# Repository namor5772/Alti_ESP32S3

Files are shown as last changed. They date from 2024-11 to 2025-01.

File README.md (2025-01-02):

This is a repository for my digital altimeter based on the ESP32-S3 microcontroller. It uses an I2C interfaced pressure/temperature sensor board based on the MS5637 chip and an 84x48 SPI interfaced lcd screen based on the PCD8544 chip. The electronics is housed in the enclosure used by an old analog skydiving altimeter. Eveything is powered by a single cell LiPo battery that can be charged by a USB-C port. This can also be used to update the software.

When switched on the altimeter sets to zero, giving the height above ground in thousands of feet or alternately relative to the standard sea level pressure of 1013.25 mb. It displays the height in large numerical characters to the nearest 100 feet, with the remaining altitude < 100 ft in a very small font. Negative altitudes are displayed as required.

In addition the voltage x 10 is displayed in a tiny font at the top right of the screen, under it is displayed the approximate air temperature also in a tiny font. If the battery voltage drop below 3.2V (32 displayed) the voltage displayed is replaced by a flashing block. "Latching" is implemented in code to prevent the display alternating with voltage and flashing block.

The switch for the altimiter is actually a momentary push button and does not physically disconnect/connect the battery from the circuit, it just toggles between the microcontrollers normal and deep sleep states. In the deep sleep state the circuit uses minimal current of around 18µA and should last about a year before recharging. In order that one does not accidentally switch the altimeter off, doing so requires the switch to be pressed twice within a very specific and narrow time gap range. This is indicated by temporary and self explanatory messages displayed on the screen.

It has been successfully tested in freefall!

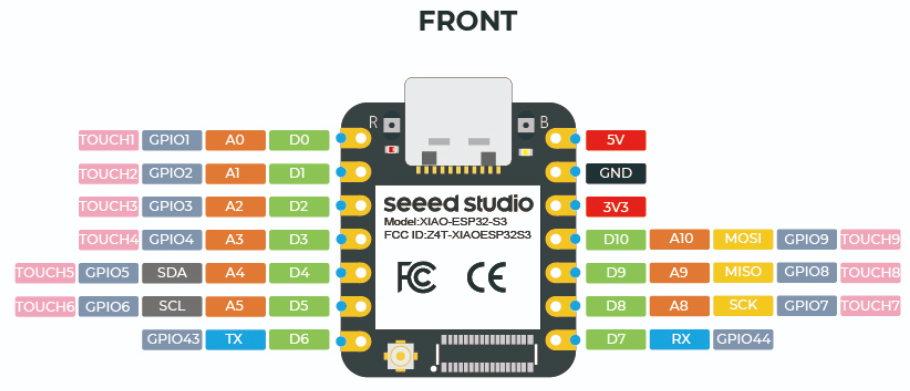
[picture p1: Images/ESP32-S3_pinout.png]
ESP32-S3 pinout


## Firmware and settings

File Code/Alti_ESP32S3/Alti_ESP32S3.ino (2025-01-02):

#include "MS5637.h"
#include "PCD8544.h"
#include "Font.h"

#include <Preferences.h>
#include <esp_sleep.h>
#include <esp32-hal-gpio.h>

// Define DEBUG to enable debug mode
#define DEBUG

// To Do :
// done 1. Make nicer big numbers font for displaying Altitude
// done 2. Test Deep-Sleep functionality
// 3. implement 3x button press Deep-Sleep functionality, with random delays

// Define the analog pin connected to the voltage divider
#define BATTERY_PIN 8 // GPIO8 (A9)

// Define the pin connected to a momentary button, to toggle
// deep-sleep mode for trhis altimeter, as an alternative to
// a physical switch that disconnects LiPo battery.
#define ONOFF_PIN 7 // GPIO7 (D8)

// Nokia 5772 - PCD8544 driver chip
// and pinout to SEED ESP32s3 MICRO
// 1 - VCC (3v3)
// 2 - GND
// 3 - SCE (CE)       - GPIO1 D0
// 4 - RST (RST)      - GPIO2 D1
// 5 - D/C (DC)       - GPIO3 D2
// 6 - DN<MOSI> (DIN) - GPIO4 D3 
// 7 - SCLK (CLK)     - GPIO9 D10
// 8 - LED 
// An instance called lcd of the PCD8544 class is created
// The module uses an enhanced bit-bashed 3-Wire SPI communications protcol
// The specified pins are: CLK, MOS, RES, DC, CS.
#define RST 2
#define CE 1
#define DC 3
#define DIN 4
#define CLK 9
PCD8544 lcd{RST, CE, DC, DIN, CLK};

// An instance of the MS5637 class called BARO is created
// The address and micro pins are defined in the MS5637.h file
// The module is I2C and has just 4 pins:
// 1 GND - connect to ground pin on micro (Seeed ESP32S3 here)
// 2 SDA - connect to SDA pin on micro (also called GPIO5 & D4)
// 3 SCL - connect to SCL pin on micro (also called GPIO6 & D5)
// 4 VCC - connect to 3V3 pin on micro
MS5637 BARO;

// *** global variables ***
bool isGround;
uint32_t chipId = 0;
uint16_t adcRaw;
float temp, pressure, altBase, altRel, batVol;
// related to safely shutting down the altimeter
int pressNum = 0;
bool keyPressed = false;
bool keyPressedAgain = false;
bool Redraw = false;
int tryNum = 0;
uint32_t startTime, elapsedTime;
int randomDelay;


void setup() {
  startTime = millis();
  Serial.begin(115200);

  // initialize digital pin LED_BUILTIN as an output
  // and turn the LED off (ie. HIGH) by default
  pinMode(LED_BUILTIN, OUTPUT);
  digitalWrite(LED_BUILTIN, HIGH);

  // setup deep-sleep on/off pin,
  // actually need an external pull-up (4.7k)
  pinMode(ONOFF_PIN,INPUT_PULLUP);

  // reads the persistent isGround boolean value
  Preferences preferences;
  preferences.begin("alti_prefs", false);
  bool isGround = preferences.getBool("isGround", false);

  // setup MS5637 sensor (An instance of the MS5637 object BARO has been constructed above)
  BARO.begin();
  BARO.dumpDebugOutput();
  BARO.getTempAndPressure(&temp, &pressure);

  // toggles mode as ground or absolute between powering altimeter
  if (isGround) {
    altBase = BARO.pressure2altitude(pressure);
    preferences.putBool("isGround", false);
  }
  else { // if not isGround
    altBase = 0.0;
    preferences.putBool("isGround", true);
  }
 
  // setup lcd screen and display splash screen for 3 seconds
  // then clear in readiness for normal data display
  lcd.setDisplayMode(NORMAL);
  lcd.setContrast(60);
  lcd.print("Alti ESP32v2.0 Nov24");
  lcd.print("----------");
  lcd.setCursor(0, 3);
  lcd.print("Roman M   Groblicki ");
  lcd.print("----------");
  delay(3000);
  lcd.clear();
}


void loop() {
  // is key pressed ?
  keyPressed = (digitalRead(ONOFF_PIN)==LOW); 


// *** START - obtaining, processing and displaying data on screen

  if (!BARO.isOK()) {
    // Try to reinitialise the sensor if we can and measure temperature and pressure
    BARO.begin();
    BARO.getTempAndPressure(&temp, &pressure);
  }
  else { // just normal measurements on each loop
    BARO.getTempAndPressure(&temp, &pressure);
  }

  // Calculate and display the altitude relative to where the altimeter was turned on
  altRel = BARO.pressure2altitude(pressure) - altBase; 
  if (altRel < 0.0) altRel = -1.0*altRel; // take the absolute value 
  lcd.Altitude_largefont(altRel, Redraw);

  // display current temperature measured by the MS5637 (and used to
  // improve calculation of air pressure above)
  temp = temp - 0.5; // fudjustment for circuit temp being above ambient
  lcd.Temperature_tinyfont(temp, 1, 76, Redraw);

  // Read raw ADC value, convert to battery voltage and display both
  adcRaw = analogRead(BATTERY_PIN);
  batVol = adcRaw*0.000903509+0.460132; // 0.287561; // raw adc to battery voltage conversion
  if (batVol>3.19){
    // just display battery voltage
    lcd.Battery_tinyfont(batVol, 0, 76, Redraw);
  }
  else { //battery voltage too low so indicate need to charge LiPo
    // flash a block in the battery voltage display position
    // half second on, half second off.
    float mTime = millis();
    mTime = mTime-floor(mTime/1000.0)*1000.0;
    bool isFlash = false;
    if (mTime<500.0) isFlash = true;
    lcd.BatteryFlash_tinyfont(isFlash, 0, 76, Redraw);
  }

// *** END - obtaining, processing and displaying data on screen

  Redraw = false;

// *** START - dealing with trying to shut down altimeter ***

  if ((pressNum > 0) && (!keyPressed)) {
    lcd.clear(); delay(50);

#ifdef DEBUG
    Serial.print(F("PRESS AGAIN "));
    Serial.println(pressNum);
#endif    

    lcd.print("----------");
    lcd.print("--PRESS---");
    lcd.print("--AGAIN---");    
    lcd.print("--NOW!!---");
    lcd.print("----------");
    lcd.print("----------");
    delay(100);

    // is key pressed again?
    tryNum = 0;
    Serial.println(tryNum);
    keyPressedAgain = (digitalRead(ONOFF_PIN)==LOW);
    while ((!keyPressedAgain) && (tryNum<10)) {
      delay(100);
      keyPressedAgain = (digitalRead(ONOFF_PIN)==LOW);
      tryNum++;
      Serial.println(tryNum);
    }
    lcd.clear();
    
    // make this delay slightly random, say between 1 and 5 seconds,
    // unless it is the 2nd press in which case can just make it 1second
    if (pressNum==2) {
      delay(1000);
    }
    else {
      randomDelay = 10*random(100,501);
      Serial.println(randomDelay);
      delay(randomDelay);
    }

    pressNum++;
    if (!keyPressedAgain) {
      Serial.println(F("MISSED"));
      lcd.print("          ");
      lcd.print("          ");
      lcd.print("  MISSED  ");
      delay(2000);
      lcd.clear();
      pressNum = 0;
      Redraw = true;
    }      
  }
  else if ((pressNum > 0) && (keyPressed)) {
    // kept button pressed too long so reset attempt to shut down
    delay(500);
    pressNum==0;
    keyPressed = false;
    Redraw = true;
  }

  if (keyPressed || keyPressedAgain ){
    if (pressNum==0) {
      // clear and display 'shutdown' screen for 2 seconds then clear again
      lcd.clear(); delay(50);
      Serial.println(F("SHUTTING DOWN INTO DEEP SLEEP"));
      lcd.print("----------");
      lcd.print("-SHUTTING-");
      lcd.print("---DOWN---");    
      lcd.print("---INTO---");
      lcd.print("DEEP SLEEP");
      lcd.print("----------");

      // make this delay slightly random, say between 1 and 5 seconds
      // we randomly seed the random generator here
      // for use here and and the next keypress.
      elapsedTime = millis() - startTime;
      randomSeed(elapsedTime);
      randomDelay = 10*random(100,501);

      Serial.println(randomDelay);
      
      delay(randomDelay);
      lcd.clear();

      pressNum = 1;
      Redraw = true;
    }
    else if (pressNum==3) {
      lcd.clear(); delay(50);
      Serial.println(F("SHUTTING DOWN FOR REAL"));
      lcd.print("----------");
      lcd.print("-SHUTTING-");
      lcd.print("---DOWN---");    
      lcd.print("--4-REAL--");
      lcd.print("----------");
      lcd.print("----------");
      delay(2000);

      // Enable EXT0 wake-up source (wake up when pin goes LOW) 
      esp_sleep_enable_ext0_wakeup(GPIO_NUM_7, 0);

      // Enter deep sleep mode 
      esp_deep_sleep_start();
    }
  } 

// *** END - dealing with trying to shut down altimeter ***

  delay(50);
}

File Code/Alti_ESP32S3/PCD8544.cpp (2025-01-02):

#include "Arduino.h"
#include "PCD8544.h"
#include "Font.h"


PCD8544::PCD8544(uint8_t RST, uint8_t CE, uint8_t DC, uint8_t DIN, uint8_t CLK):
  _RST(RST), _CE(CE), _DC(DC), _DIN(DIN), _CLK(CLK) {

  pinMode(RST, OUTPUT);
  pinMode(CE, OUTPUT);
  pinMode(DC, OUTPUT);
  pinMode(DIN, OUTPUT);
  pinMode(CLK, OUTPUT);

  // screen initializations  
  reset();
  clear();
  setDisplayMode(NORMAL);
  setBiasSystem(FORTY);
  setContrast(60);

  // initialise str_old*, for its first use in loop(),
  // size is enough to store 10 characters, but often less is used.
  for (int i=0; i<10; i++) {
    str_old[i] = ' ';  
    str_old0[i] = ' ';
    str_old1[i] = ' ';
    str_old2[i] = ' ';
    str_old3[i] = ' ';
    str_old4[i] = ' ';
  }        
}

// contrast c should be between 0x00 and 0x7F inclusive (127 decimal) 
void PCD8544::setContrast(uint8_t c){
    digitalWrite(_CE, LOW); // CS (Upper score)
    digitalWrite(_DC, LOW); // select Command Mode - A0 set as LOW
    shiftOut(_DIN, _CLK, MSBFIRST, ADVANCED); // use extended instruction set
    shiftOut(_DIN, _CLK, MSBFIRST, byte(0x80 + c));
    digitalWrite(_CE, HIGH);
}

// Temperature Coefficient value could be one of 0, 1, 2 or 3;
void PCD8544::setTemperatureCoefficient(uint8_t value){
    digitalWrite(_CE, LOW); // CS (Upper score)
    digitalWrite(_DC, LOW); // select Command Mode - A0 set as LOW
    shiftOut(_DIN, _CLK, MSBFIRST, ADVANCED); // use extended instruction set
    shiftOut(_DIN, _CLK, MSBFIRST, byte(0x04 + value));
    digitalWrite(_CE, HIGH);
}

void PCD8544::setCursor(uint8_t x, uint8_t y){
    Xcur = x; Ycur = y;
    digitalWrite(_CE, LOW); // CS (Upper score)
    digitalWrite(_DC, LOW); // select Command Mode - A0 set as LOW
    shiftOut(_DIN, _CLK, MSBFIRST, BASIC); // use basic instruction set
    shiftOut(_DIN, _CLK, MSBFIRST, byte(0x80 + x)); //set x position
    shiftOut(_DIN, _CLK, MSBFIRST, byte(0x40 + y)); //set y position
    digitalWrite(_CE, HIGH);
}

void PCD8544::clear(){
    Xcur = 0; Ycur = 0;
    digitalWrite(_CE, LOW); // CS (Upper score)
    digitalWrite(_DC, LOW); // select Command Mode - A0 set as LOW
    shiftOut(_DIN, _CLK, MSBFIRST, BASIC); // use basic instruction set
    shiftOut(_DIN, _CLK, MSBFIRST, byte(0x80)); //set x position to 0
    shiftOut(_DIN, _CLK, MSBFIRST, byte(0x40)); //set y position to 0
    digitalWrite(_DC, HIGH); // select Data Mode - A0 set to HIGH
        for (int i=0; i<504; i++) shiftOut(_DIN, _CLK, MSBFIRST, 0x00);
    digitalWrite(_CE, HIGH);
    // at this point cursor has cycled back to (0,0)
}

void PCD8544::setDisplayMode(byte value){
    digitalWrite(_CE, LOW); // CS (Upper score)
    digitalWrite(_DC, LOW); // select Command Mode - A0 set as LOW
    shiftOut(_DIN, _CLK, MSBFIRST, BASIC); // use basic instruction set
    shiftOut(_DIN, _CLK, MSBFIRST, value); // set display configuration
    digitalWrite(_CE, HIGH);
}

void PCD8544::setBiasSystem(byte rate){
    digitalWrite(_CE, LOW); // CS (Upper score)
    digitalWrite(_DC, LOW); // select Command Mode - A0 set as LOW
    shiftOut(_DIN, _CLK, MSBFIRST, ADVANCED); // use extended instruction set
    shiftOut(_DIN, _CLK, MSBFIRST, rate); // set bias system
    digitalWrite(_CE, HIGH);
}

// displays a block of data to screen, at top-left-hand position (page, col),
// ie pixel row is pagex8 and pixel column is col.
// the height is pages high (ie pagesx8 pixels) and cols pixels wide.
// the data (in vertical-encoding) is stored in a 1d array of bytes called Arr,
// while the offset for individual bytes (to display) is address which has to be uint16_t
// since the array might have more than 256 elements.
void PCD8544::writeBlock(uint8_t page, uint8_t col, uint8_t pages, uint8_t cols, uint16_t address, const uint8_t Arr[]) {
  uint8_t columnByte;
  digitalWrite(_CE, LOW); // CS (Upper score)
  for (uint8_t j = 0; j < pages; j++) {
    digitalWrite(_DC, LOW); // select Command Mode - A0 set as LOW
    shiftOut(_DIN, _CLK, MSBFIRST, BASIC); // use basic instruction set
    shiftOut(_DIN, _CLK, MSBFIRST, byte(0x80 + col));      //set x position
    shiftOut(_DIN, _CLK, MSBFIRST, byte(0x40 + page + j)); //set y position

    digitalWrite(_DC, HIGH); // Datamode - A0 set to HIGH
    for (uint8_t i = 0; i < cols; i++)  {
      columnByte = pgm_read_byte(&Arr[address + cols*j + i]);
      shiftOut(_DIN, _CLK, MSBFIRST, columnByte);
    }
  }
  digitalWrite(_CE, HIGH);
}

void PCD8544::write8x8Char(uint8_t page, uint8_t column, uint16_t charCode, const uint8_t Arr[][8]) {
  uint8_t columnByte;
  digitalWrite(_CE, LOW); // CS (Upper score)

  digitalWrite(_DC, LOW); // select Command Mode - A0 set as LOW
  shiftOut(_DIN, _CLK, MSBFIRST, BASIC); // use basic instruction set
  shiftOut(_DIN, _CLK, MSBFIRST, byte(0x80 + column)); //set x position
  shiftOut(_DIN, _CLK, MSBFIRST, byte(0x40 + page));   //set y position

  digitalWrite(_DC, HIGH); // Datamode - A0 set to HIGH
  for (uint8_t i = 0; i < 8; i++)  {
    columnByte = pgm_read_byte(&Arr[charCode][i]);
    shiftOut(_DIN, _CLK, MSBFIRST, columnByte);
  }

  digitalWrite(_CE, HIGH);
}

// generate and display formatted string for temperature temp_,
// but for speed only redisplay changed characters.
void PCD8544::Temperature(float temp_, uint8_t page, uint8_t col) {
  int w = 5; // width of text in characters
  if (temp_<=-10.0) {
    dtostrf(temp_,3,0,str_new0);  
    str_new0[3] = 0x00; // degree character
    w--;
  } else {
    dtostrf(temp_,4,1,str_new0);
    str_new0[4] = 0x00; // degree character
  }
  for (int i=0; i<w; i++) {
    if (str_new0[i] != str_old0[i]) {
      write8x8Char(page, col+i*8, str_new0[i], Font8x8_);
      str_old0[i] = str_new0[i]; // after loop finish make str_old0 the current str_new0
    }      
  }
}

// generate and display formatted string for temperature temp_,
// but for speed only redisplay changed characters.
// minimal display using only 2 chars with 0dp. if <=-10 then no sign.
void PCD8544::Temperature_tinyfont(float temp_, uint8_t page, uint8_t col, bool Redraw) {
  if (temp_<=-10.0) temp_ = -1.0 * temp_*-1.0;
  dtostrf(temp_,2,0,str_new0);
  str_new2[2] = 0;  
  for (int i=0; i<2; i++) {
    if ((str_new0[i] != str_old0[i]) || Redraw) {
      writeBlock(page, col+4*i, 1, 4,  ASCII2offset(str_new0[i], 0x0004), FontNums3x5);
      str_old0[i] = str_new0[i]; // after loop finish make str_old0 the current str_new0
    }      
  }
}


// display battery voltage to 2dp, using 8x8 font.
void PCD8544::Battery_smallfont(float battery, uint8_t page, uint8_t col, bool Redraw) {
  dtostrf(battery,4,2,str_new2);
  str_new2[4] = 'v';
  for (int i=0; i<5; i++) {
    if ((str_new2[i] != str_old2[i]) || Redraw) { 
      write8x8Char(page, col+i*8, str_new2[i], Font8x8_);
      str_old2[i] = str_new2[i]; // after loop finish make str_old2 the current str_new2
    }      
  }
}
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
